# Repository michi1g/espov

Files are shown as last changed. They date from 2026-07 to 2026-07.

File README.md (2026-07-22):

# MiniPOV WiFi

ESP8266-Nachbau des [Adafruit MiniPOV3](https://learn.adafruit.com/minipov3) mit WiFi-Web-Editor, **2×AA-Betrieb** und optionalem **USB-C**.

## Features

- 8-LED-POV-Display (Persistence of Vision)
- **2× AA** wie beim Original (+ Boost-Wandler auf 5 V)
- **USB-C** optional auf der Platine (Laden ohne Micro-USB-Kabel am Wemos)
- WiFi **nur bei Bedarf** – FLASH-Taste, Auto-Timeout nach 3 Min.
- Web-Editor: Pixel, Text, Bild-Upload, Vorschau

## Bedienung

### POV anzeigen (Standard)

1. Einschalten (Batterie oder USB-C)
2. Gerät schwenken – gespeichertes Muster erscheint
3. WiFi ist **aus** → maximale Batterielaufzeit

### Muster ändern

1. **FLASH-Taste** am Wemos D1 Mini drücken → WiFi-AP startet
2. Mit **`MiniPOV-WiFi`** verbinden (Passwort: `minipov123`)
3. Browser: **http://192.168.4.1**
4. Muster gestalten → **An Gerät senden**
5. **WiFi beenden** (Web-UI oder FLASH-Taste) → zurück zum POV-Modus

Nach 3 Minuten ohne Aktivität schaltet WiFi automatisch ab.

## Hardware

Stückliste, Boost-Einstellung, USB-C-Platzierung: **[docs/HARDWARE.md](docs/HARDWARE.md)**

KiCad-Platinenlayout (28×118 mm, USB-C an Griffseite): **[docs/KICAD.md](docs/KICAD.md)** · Projekt in `hardware/kicad/`

Kurz:

- 2×AA → Boost 5 V → Wemos 5V-Pin
- USB-C 5 V parallel (mit Schottky-Diode)
- 8× LED + 100 Ω wie MiniPOV3

## Software flashen

[PlatformIO](https://platformio.org/) (VS Code Extension):

```bash
pio run -t upload      # Firmware
pio run -t uploadfs    # Web-Oberfläche
pio device monitor
```

Erstes Flashen bequem über **Micro-USB am Wemos** (USB-C auf Platine reicht danach für Strom).

## Konfiguration

`src/config.h`:

| Konstante | Standard | Bedeutung |
|---|---|---|
| `WIFI_AP_TIMEOUT_MS` | 180000 | AP-Dauer (3 Min.) |
| `CPU_FREQ_POV_MHZ` | 80 | CPU im POV-Modus |
| `CONFIG_BUTTON_PIN` | 0 | FLASH-Taste |

## Projektstruktur

```
mini-pov-wifi/
├── data/           # Web-UI (LittleFS)
├── docs/           # Hardware-Doku
├── src/
│   ├── wifi_manager.*   # WiFi ein/aus, Timeout
│   ├── pov_engine.*     # LED-Timing
│   └── web_server.*     # REST + Editor
└── platformio.ini
```

## Lizenz

MIT – inspiriert vom Adafruit MiniPOV3.

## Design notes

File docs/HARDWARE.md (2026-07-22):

# MiniPOV WiFi – Hardware

ESP8266-POV im Stil des [Adafruit MiniPOV3](https://learn.adafruit.com/minipov3), mit **2×AA-Betrieb**, optionalem **USB-C** und WiFi nur bei Bedarf.

## Stromversorgung – Übersicht

```
  2×AA (2,0–3,2 V)
       │
       ▼
  ┌─────────────┐
  │ Boost 5 V   │───|>───┐
  │ (MT3608 o.ä.)│       │
  └─────────────┘       ├──► 5 V Rail ──► Wemos D1 Mini (5V-Pin)
                        │
  USB-C Breakout 5 V ──|>──┘
       │
      GND ═══════════════════════ GND (gemeinsame Masse)
```

**Wichtig:** 2×AA **niemals** direkt an 5 V oder 3,3 V – der ESP8266 braucht einen **Boost-Wandler** (2×AA → 5 V).

Der Wemos D1 Mini hat einen onboard AMS1117 (5 V → 3,3 V). Beide Quellen speisen den **5V-Pin** über Schottky-Dioden (Verpolungsschutz + Quellenumschaltung).

| Quelle | Spannung | Anschluss | Verwendung |
|---|---|---|---|
| 2× AA | 2,0–3,2 V | → Boost → 5 V Rail | POV unterwegs |
| USB-C | 5 V | Breakout → 5 V Rail | Laden/Programmieren am PC |
| Wemos Micro-USB | 5 V | onboard | Entwicklung (parallel möglich) |

### Erwartete Laufzeit (2×AA, alkalisch)

| Modus | Strom ca. | Laufzeit ca. |
|---|---|---|
| POV, WiFi **aus** | 50–80 mA | **3–6 h** |
| Konfiguration, WiFi **an** | 120–180 mA | **1–2 h** gesamt* |

\*WiFi ist standardmäßig aus und nur 3 Minuten aktiv (FLASH-Taste). So bleibt die Batterie lange im POV-Modus.

## Stückliste (BOM)

| Menge | Bauteil | Beschreibung | Bezugsquelle / Hinweis |
|---:|---|---|---|
| 1 | Wemos D1 Mini | ESP8266, 3,3 V-Regler | |
| 8 | 5 mm LED rot, diffus | wie MiniPOV3 | Kathode zur Plattenkante |
| 8 | 100 Ω, 1/4 W | LED-Strombegrenzung | |
| 1 | Batteriehalter **2× AA** | wie Original-MiniPOV | |
| 1 | Boost-Modul **5 V** | MT3608, Pololu U1V10F5 o.ä. | Ausgang auf **5,0 V** einstellen |
| 2 | Schottky-Diode | 1N5817, SS14 | Boost + USB-C zum 5V-Rail |
| 1 | USB-C-Breakout | 16-Pin, **nur 5 V + GND** | siehe USB-C-Abschnitt |
| 1 | 100 µF Elko | 6,3 V+ | nahe 5V-Rail (Puffer) |
| 1 | 100 nF Keramik | | nahe Wemos 3,3 V |
| 1 | Lochrasterplatine | ca. 50×70 mm | oder eigene PCB |
| 2 | Stiftleiste 8-polig | female | Wemos steckbar |
| — | Litzenkabel | | |

**Nicht nötig:** 3×AA, Zener-Dioden (MiniPOV3-Programmer), extra Programmer.

## Boost-Wandler einstellen

1. Boost ** ohne Last** an 2×AA oder Labornetzgerät (2,5 V) hängen.
2. Multimeter an Boost-Ausgang: Poti drehen bis **5,0 V** (max. 5,2 V).
3. Erst dann mit Wemos verbinden.

Empfehlung: MT3608-Modul mit USB-Ausgang **nicht** verwenden – feste 5-V-Module oder einstellbare Boosts mit Multimeter-Abgleich.

## USB-C – Anschluss & Platzierung

Es wird ein einfaches **USB-C-Breakout-Board** (nur Strom, ohne Daten) genutzt – gut lötbar, kein SMD-Löten am Stecker selbst.

### Anschluss

| USB-C Breakout | MiniPOV-Platine |
|---|---|
| VBUS (5 V) | → Schottky-Anode → 5 V Rail |
| GND | → GND |

**Keine Datenleitung nötig** – Programmierung läuft weiter über den Micro-USB des Wemos oder UART.

### Platzierungs-Optionen

```
Option A – Griffende (empfohlen)          Option B – Unterseite
┌──────────────────────────┐              ┌──────────────────────────┐
│  LED LED LED LED LED ... │              │  LED LED LED LED LED ... │
│  [Wemos]    [Boost]      │              │  [Wemos]    [Boost]      │
│  ═══ Batterie 2×AA ═══   │              │  ═══ Batterie 2×AA ═══   │
│              [USB-C]─────┤              │  ──────[USB-C]────────── │  ← flach, Kabel von unten
└──────────────────────────┘              └──────────────────────────┘

Option C – Seitenkante                    Option D – neben Wemos
┌──────────────────────────┐              ┌──────────────────────────┐
│[USB-C]                   │              │ [USB-C] [Wemos] [Boost]  │
│  LED LED LED LED ...     │              │  LED LED LED LED ...     │
└──────────────────────────┘              └──────────────────────────┘
```

| Option | Vorteil | Nachteil |
|---|---|---|
| **A – Griffende** | Kabel stört nicht beim Schwenken | etwas mehr Länge |
| **B – Unterseite** | kompakte Bauform | Kabel unter der Hand |
| **C – Seitenkante** | kurzer Steckerweg | evtl. Wackelkontakt |
| **D – neben Wemos** | kurze Leiterbahnen | weniger Platz für Boost |

**Tipp:** USB-C-Breakout mit **Lochbohrungen** (2,54 mm Raster) auf die Platine schrauben/löten – hält mechanisch besser als nur 2 Drähte.

### USB-C vs. Micro-USB am Wemos

| Anschluss | Wofür |
|---|---|
| **USB-C auf Platine** | Alltagsladung, Powerbank, Netzteil – ergonomisch platziert |
| **Micro-USB am Wemos** | Firmware flashen während der Entwicklung |

Beide können parallel an die 5-V-Rail (jeweils mit Schottky). Beim gleichzeitigen Anschließen gewinnt die höhere Spannung; Schottkys verhindern Rückspeisung in Boost oder USB-C-Quelle.

## Schaltplan (Detail)

```
                    ┌─────────────────────────────────────┐
  Boost OUT ──|>────┤ 5V                                  │
                    │         ┌──────────────┐            │
  USB-C 5V ───|>────┤         │ Wemos D1 Mini│            │
                    │    5V──►│              │            │
  (Micro-USB) ──────┤         │ D1..D0 ──────┼──► 8× LED │
                    │    GND──┤              │            │
  2×AA ──► Boost IN │         └──────────────┘            │
  GND ══════════════╧═════════════════════════════════════┘

  LED: GPIO → 100Ω → Anode → Kathode → GND
```

## Pinbelegung (LEDs)

| LED | D-Pin | GPIO | Boot-Hinweis |
|----:|---|---|---|
| 1 | D1 | GPIO5 | — |
| 2 | D2 | GPIO4 | — |
| 3 | D4 | GPIO2 | onboard LED |
| 4 | D5 | GPIO14 | — |
| 5 | D6 | GPIO12 | HIGH beim Boot (LED aus) |
| 6 | D7 | GPIO13 | — |
| 7 | D8 | GPIO15 | LOW beim Boot (LED aus) |
| 8 | D0 | GPIO16 | — |

**Konfig-Taste:** onboard **FLASH** (GPIO0) – WiFi ein/aus, siehe README.

## Löten – Reihenfolge

1. USB-C-Breakout und Batteriehalter an der gewählten Position fixieren.
2. Boost-Modul löten (Eingang ← 2×AA, Ausgang → Schottky → 5V-Rail).
3. Schottkys und 100 µF an der 5V-Rail.
4. 8× Widerstand + 8× LED (Kathode zur Außenkante).
5. Wemos auf Stiftleiste setzen, 5V + GND + LED-Drähte verbinden.
6. Boost-Spannung ** ohne Wemos** auf 5,0 V einstellen, dann Wemos stecken.
7. Test: USB-C → LEDs blinken, POV ok; Batterie → dasselbe.

## WiFi / Batterie sparen (Firmware)

| Zustand | Verhalten |
|---|---|
| **POV-Modus** (Standard) | WiFi aus, 80 MHz CPU, Muster läuft |
| **Konfig-Modus** | FLASH-Taste → AP 3 Min., dann automatisch aus |
| **Web-Aktivität** | Timer +1 Minute pro Speichern/Abruf |
| **Web-UI** | „WiFi beenden“ schaltet sofort ab |

## KiCad-Platine

Fertiges Layout-Projekt (28×118 mm, USB-C an Griffseite): **[KICAD.md](KICAD.md)** in `hardware/kicad/`

## Mechanik

Vier Bohrlöcher (wie MiniPOV3) für Montage an Stab/Fahrrad. USB-C an der **Griffseite** platzieren, damit das Ladekabel beim Schwenken nicht über die LEDs hängt.

## Sicherheit

- Boost-Ausgang ** nie** über 5,2 V einstellen.
- Schottkys nicht vergessen (Boost ↔ USB-C).
- Kurzschluss an Batterie vermeiden – Boost zieht sonst hohen Strom.
- Beim Löten am Wemos Hitze kurz halten.

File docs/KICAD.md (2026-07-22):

# KiCad – MiniPOV WiFi Platine

Platinen-Skizze im MiniPOV3-Formfaktor mit **USB-C an der Griffseite** und Platz für **2×AA + Boost**.

## Dateien

```
hardware/kicad/
├── mini-pov-wifi.kicad_pro    ← Projekt öffnen
├── mini-pov-wifi.kicad_sch    ← Blocksdiagramm / Verdrahtungshinweise
├── mini-pov-wifi.kicad_pcb    ← Layout-Skizze (v0.1)
├── mini-pov-wifi.kicad_sym    ← Lokale Symbole
├── mini-pov-wifi.pretty/      ← Footprints (THT, lötbar)
├── fp-lib-table
└── sym-lib-table
```

**KiCad 7 oder 8** empfohlen. Projektordner `hardware/kicad/` in KiCad öffnen.

## Platinenmaß

| Parameter | Wert |
|---|---|
| Größe | **28 × 118 mm** |
| Dicke | 1,6 mm |
| Form | schmaler Stab (MiniPOV-artig, Mitte verbreitert für Wemos) |
| Löcher | 4× 3,2 mm Montage (wie MiniPOV3) |

## Layout (Draufsicht)

```
  TIP ── LEDs schauen nach links (Kathode ←)

        ┌── LED-Reihe (D1–D8) ──────────────┐
        │  ● ● ● ● ● ● ● ●                  │  Y ≈ 8–61 mm
        │  R  R  R  R  R  R  R  R            │  Widerstände rechts
        │                                   │
        │      ┌─────────────┐              │
        │      │ Wemos D1    │              │  Y ≈ 68–96 mm
        │      │ Mini U2     │              │
        │      └─────────────┘              │
        │   [ MT3608 U1 ]  C1  D9 D10       │  Y ≈ 92 mm
        │      ( Boost )                    │
        │   [ 2×AA BT1 ]                    │  Y ≈ 102 mm
        │   ┌──────────┐                    │
  GRIFF │   │ USB-C J2 │                    │  Y ≈ 108 mm  ← hier laden
        └───┴──────────┴────────────────────┘
            H3                    H4
     H1                              H2  (Montagelöcher)
```

**Schwenkrichtung:** Griff unten halten, LEDs oben/links – wie beim Original-MiniPOV.

## Bauteil-Platzierung

| Ref | Bauteil | Position (ca.) | Hinweis |
|-----|---|---|---|
| D1–D8 | 5 mm LED | Spitze, 7,62 mm Pitch | 90° gedreht, Kathode zum linken Rand |
| R1–R8 | 100 Ω | rechts neben LEDs | GPIO → R → LED-Anode |
| U2 | Wemos D1 Mini | Mitte | 2×8 Stiftleisten, steckbar |
| U1 | MT3608-Modul | vor Griff | Ausgang auf **5,0 V** einstellen |
| BT1 | 2×AA-Anschluss | über Boost | +/- Litzen |
| J2 | USB-C-Breakout | **Griffseite** | nur VBUS + GND |
| D9, D10 | 1N5817 Schottky | nahe Boost | noch manuell platzieren / routen |
| C1 | 100 µF | nahe 5V-Rail | |
| C2 | 100 nF | nahe Wemos | |
| H1–H4 | 3,2 mm Bohrung | Ecken | Stab/Fahrrad-Montage |

## GPIO → LED (Firmware)

| LED | Wemos Pin | GPIO |
|----:|---|---|
| D1 | D1 | GPIO5 |
| D2 | D2 | GPIO4 |
| D3 | D4 | GPIO2 |
| D4 | D5 | GPIO14 |
| D5 | D6 | GPIO12 |
| D6 | D7 | GPIO13 |
| D7 | D8 | GPIO15 |
| D8 | D0 | GPIO16 |

## Nächste Schritte in KiCad

1. **Projekt öffnen** → PCB Editor
2. **D9, D10, C1, C2** Footprints aus `Device`-Library setzen und platzieren
3. **Netliste** aus Schematic aktualisieren (oder manuell routen wie Skizze)
4. **DRC** ausführen, Leiterbahnen vervollständigen
5. **3D-Ansicht** prüfen: USB-C-Stecker ragt am Griff heraus
6. **Gerber exportieren** (JLCPCB, PCBWay, …)

## Footprint anpassen

Falls dein USB-C-Breakout abweicht: Footprint `USB-C_Breakout` in `mini-pov-wifi.pretty/` editieren (Bohrabstand messen!).

MT3608-Module variieren leicht in der Größe – Pin-Abstand vor dem Löten prüfen.

## Bestellung

| Layer | Empfehlung |
|---|---|
| Kupfer | 1 Lage (F.Cu) reicht |
| Farbe | deine Wahl |
| Oberfläche | HASL oder ENIG |
| Stärke | 1,6 mm |

**THT-only** (außer optional SMD-Schottkys) – gut für Anfänger-Lötkurse.

## Export

```bash
# KiCad CLI (falls installiert)
kicad-cli pcb export gerbers hardware/kicad/mini-pov-wifi.kicad_pcb -o hardware/gerbers/
kicad-cli pcb export svg hardware/kicad/mini-pov-wifi.kicad_pcb -o hardware/exports/
```

## Status v0.1

Diese Version ist eine **Platzier-Skizze**:

- Board-Umriss und Bauteile platziert
- Strom-Rückgrat (+5V/GND) angedeutet
- Schottky-Dioden und Kondensatoren als Silkscreen-Hinweis
- Vollständiges Routing und ERC/DRC musst du in KiCad abschließen

Bei Fragen zur Verdrahtung: [HARDWARE.md](../HARDWARE.md)

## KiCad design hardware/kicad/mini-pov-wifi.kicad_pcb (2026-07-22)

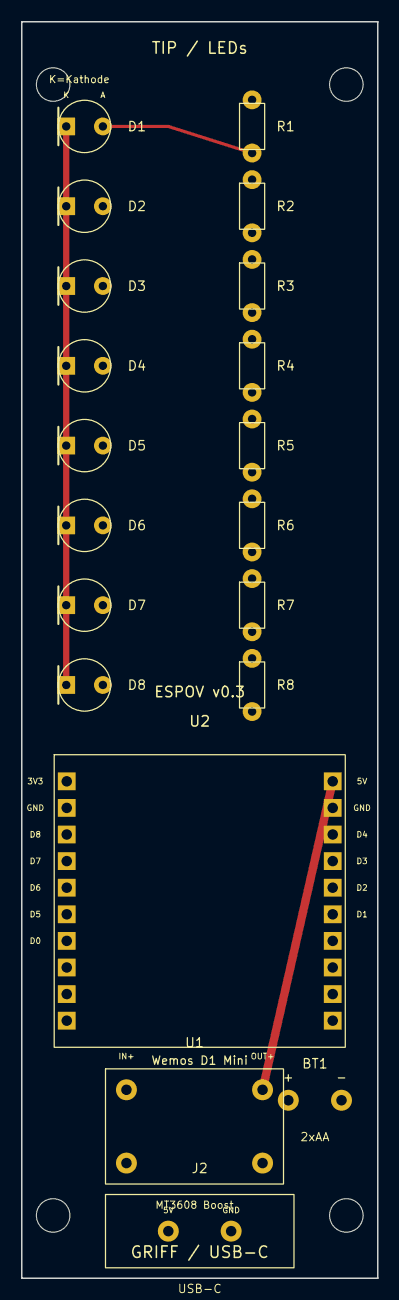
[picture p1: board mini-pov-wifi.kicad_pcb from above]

Board: 2 copper layers, 34.0 x 120.0 mm, 24 parts (0 on the bottom side), 20 nets.

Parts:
BT1: 2xAA; Battery_2xAA
D1, D2, D3, D4, D5, D6, D7, D8: LED; LED_D5.0mm
H1, H2, H3, H4: M3; MountingHole_3.2mm
J2: USB-C; USB-C_Breakout
R1, R2, R3, R4, R5, R6, R7, R8: 100R; R_THT_1-4W
U1: MT3608 Boost; MT3608_Module
U2: Wemos D1 Mini; Wemos_D1_Mini_Socket

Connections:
+5V: J2.VBUS, U1.OUT+, U2.5V
BAT+: BT1.+, U1.IN+
BAT-: BT1.-, U1.IN-
GND: D1.K, D2.K, D3.K, D4.K, D5.K, D6.K, D7.K, D8.K, J2.GND, U1.OUT-, U2.GND1, U2.GND2
GPIO_D0: R8.1, U2.D0
GPIO_D1: R1.1, U2.D1
GPIO_D2: R2.1, U2.D2
GPIO_D4: R3.1, U2.D4
GPIO_D5: R4.1, U2.D5
GPIO_D6: R5.1, U2.D6
GPIO_D7: R6.1, U2.D7
GPIO_D8: R7.1, U2.D8
LED1: D1.A, R1.2
LED2: D2.A, R2.2
LED3: D3.A, R3.2
LED4: D4.A, R4.2
LED5: D5.A, R5.2
LED6: D6.A, R6.2
LED7: D7.A, R7.2
LED8: D8.A, R8.2

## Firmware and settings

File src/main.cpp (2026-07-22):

#include <Arduino.h>
#include <LittleFS.h>
#include <WiFi.h>
#include "config.h"
#include "pattern_manager.h"
#include "pov_engine.h"
#include "web_server.h"
#include "wifi_manager.h"

PatternManager patterns;
PovEngine pov;
WebServerApp web;
WifiManager wifiMgr;

void setup() {
  Serial.begin(115200);
  delay(100);
  Serial.println();
  Serial.println(F("MiniPOV WiFi – ESP8266 (2×AA-optimiert)"));

  pov.begin();

  if (!patterns.begin()) {
    Serial.println(F("LittleFS mount failed – formatting..."));
    LittleFS.format();
    patterns.begin();
  }

  pov.setPattern(patterns.data(), patterns.width());
  pov.setColumnDelayUs(patterns.columnDelayUs());

  web.begin(&patterns, &pov, &wifiMgr);
  wifiMgr.begin(&web);
}

void loop() {
  wifiMgr.tick();
  if (wifiMgr.isApActive()) {
    yield();
  }
  pov.tick();
}

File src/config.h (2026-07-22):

#pragma once

#include <Arduino.h>
#include "config.h"

// Wemos D1 Mini onboard FLASH button (GPIO0, active LOW)
static const uint8_t CONFIG_BUTTON_PIN = 0;

// WiFi AP auto-off after inactivity (milliseconds)
static const uint32_t WIFI_AP_TIMEOUT_MS = 180000; // 3 minutes
static const uint32_t WIFI_AP_ACTIVITY_EXTEND_MS = 60000; // +1 min per save/status

// CPU frequency (MHz) – lower when WiFi off saves power on 2×AA
static const uint8_t CPU_FREQ_POV_MHZ = 80;
static const uint8_t CPU_FREQ_WIFI_MHZ = 160;

// Power: feed Wemos 5V pin from boost (2×AA) or USB-C (see docs/HARDWARE.md)
// Do NOT connect 2×AA directly to 5V without boost.

// Default timing: microseconds between columns while displaying
static const uint16_t DEFAULT_COLUMN_US = 1200;
static const uint16_t MIN_COLUMN_US = 400;
static const uint16_t MAX_COLUMN_US = 5000;

// Pattern limits
static const uint16_t MAX_PATTERN_WIDTH = 256;
static const uint8_t PATTERN_HEIGHT = 8;

// WiFi access point
static const char *WIFI_AP_SSID = "MiniPOV-WiFi";
static const char *WIFI_AP_PASS = "minipov123";

// LittleFS paths
static const char *PATTERN_FILE = "/pattern.json";

// Wemos D1 Mini GPIO pins for 8 POV LEDs (D1, D2, D4, D5, D6, D7, D8, D0)
static const uint8_t LED_PINS[8] = {5, 4, 2, 14, 12, 13, 15, 16};

enum class WifiMode : uint8_t { Off, ConfigAp };

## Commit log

2026-07-22 Initial commit: ESP8266 POV display with WiFi web editor, 2xAA power design, and KiCad PCB sketch.
    [mini-pov-wifi.kicad_pcb, mini-pov-wifi.kicad_sch]
2026-07-22 Fix KiCad PCB syntax: remove invalid comments and embed footprint pads.
    [mini-pov-wifi.kicad_pcb]
2026-07-22 Fix KiCad schematic syntax for effects and hide properties.
    [mini-pov-wifi.kicad_sch]
2026-07-22 Fix KiCad PCB hide syntax and expand schematic with standard symbols.
    [mini-pov-wifi.kicad_pcb, mini-pov-wifi.kicad_sch]
2026-07-22 Fix KiCad 8 PCB net syntax: pads and segments require net names.
    [mini-pov-wifi.kicad_pcb]
2026-07-22 Fix KiCad segments: net number only, name is for pads.
    [mini-pov-wifi.kicad_pcb]
2026-07-22 Ignore KiCad lock and history files.
2026-07-22 Clean PCB layout: single LED column, readable silk labels, A/K marks.
    [mini-pov-wifi.kicad_pcb]
2026-07-22 Rebuild schematic: power, Wemos, and full 8-LED array with embedded symbols.
    [mini-pov-wifi.kicad_sch]
